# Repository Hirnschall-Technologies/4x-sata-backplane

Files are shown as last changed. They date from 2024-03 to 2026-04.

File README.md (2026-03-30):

## Custom 4x SATA Backplane for home-nas and servers
If you are interested in the design process behind this pcb, take a look at [this accompanying blog post.](https://blog.hirnschall.net/4x-sata-backplane)

### Why use a backplane
Using a backplane allows multiple disks to be connected to a single power-supply cable. For this a 4-pin molex connector is used as it can sustain the spinup current of 4 disks.

### How to order    
Download the the latest gerber-files from the [release tab](https://github.com/shirnschall/4x-sata-backplane/releases). Order then on e.g. jlcpcb.com.     
Use the following settings when ordering:
- PCB thickness: 1.6mm
- Layers: 4
- Impedance Control: yes, JLC04161H-7628
- Material type: FR4-Standard TG 135-140
- Copper weight: 1oz outer, 0.5oz inner
- Remove Order Number: Specify a location (remove if you want to)

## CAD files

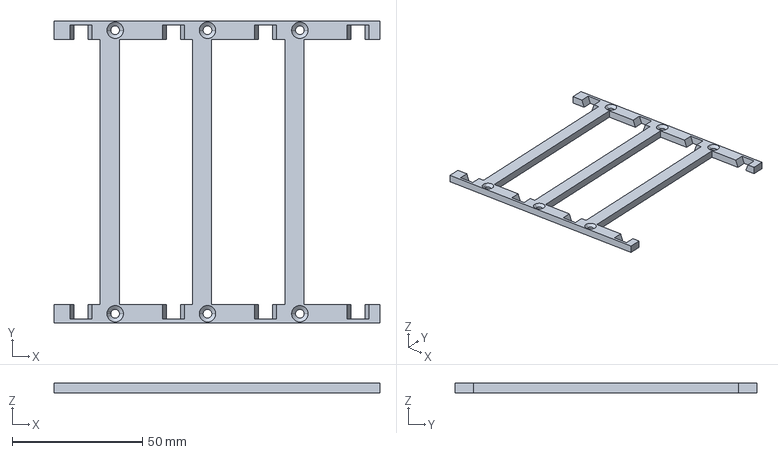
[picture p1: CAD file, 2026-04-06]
3d-print/stp/drive-cage-top.stp
125.0 x 115.7 x 4.00 mm

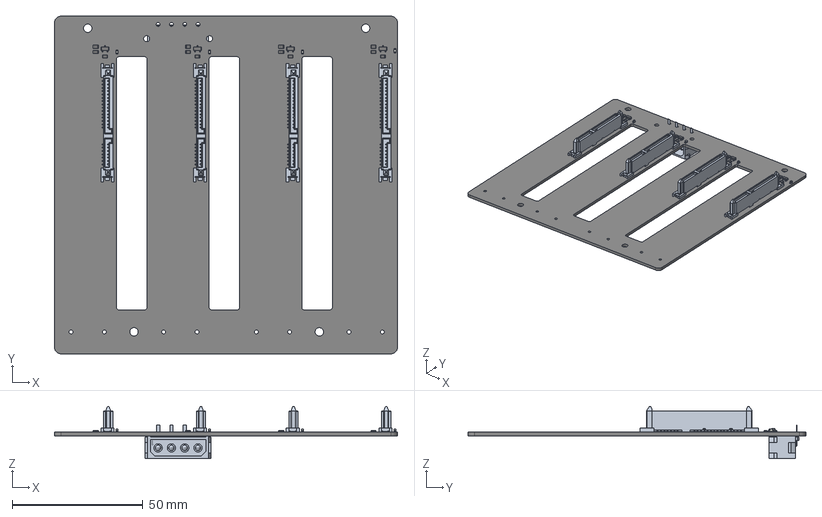
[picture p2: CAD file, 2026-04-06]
8x-sata-backplane/stp/4x-sata-backplane.step
131.0 x 129.0 x 20.0 mm
R_0805_2012Metric x 12
LED_0603_1608Metric x 4
SOT-23 x 4
8x-sata-backplane_PCB

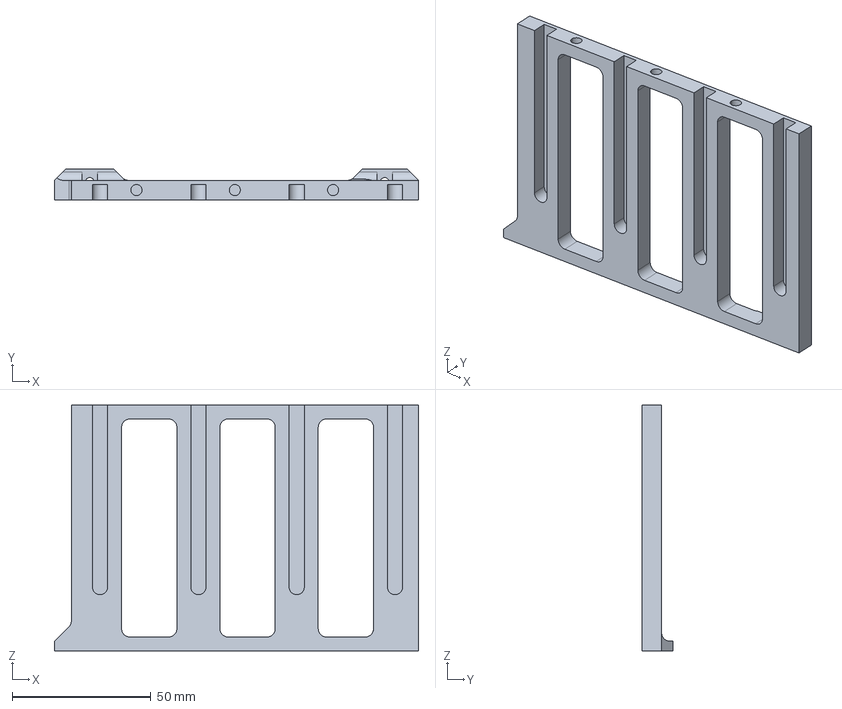
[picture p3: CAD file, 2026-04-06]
3d-print/stp/drive-cage.stp
131.0 x 11.0 x 88.5 mm

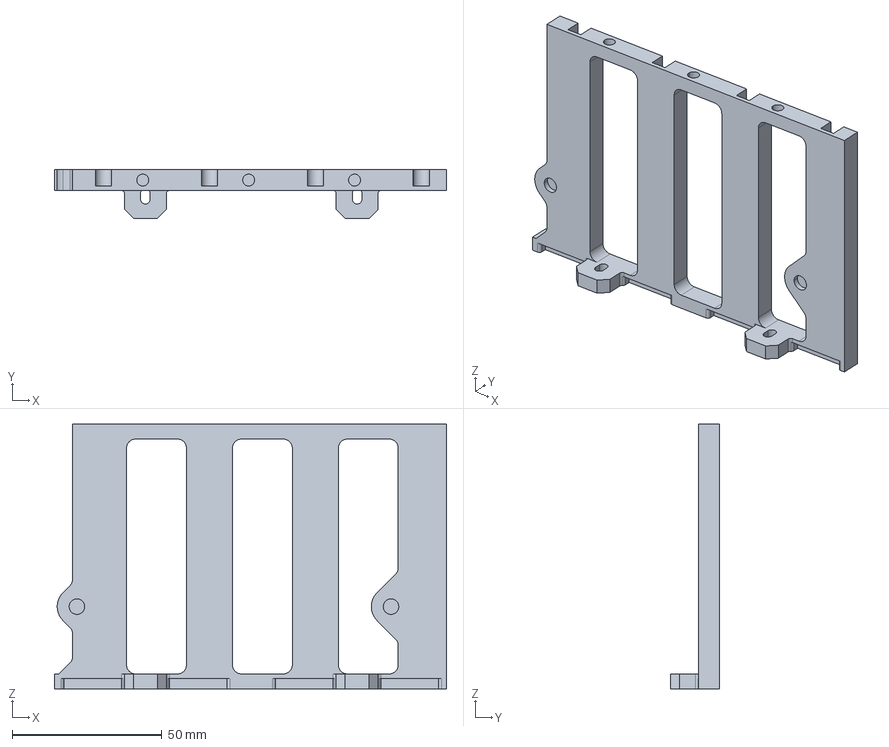
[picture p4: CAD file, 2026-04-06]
3d-print/stp/drive-cage-front.stp
131.0 x 16.3 x 88.5 mm

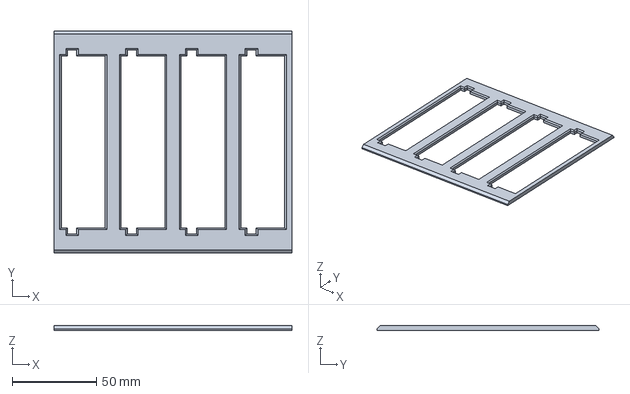
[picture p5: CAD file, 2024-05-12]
3d-print/stp/top-cover.stp
141.3 x 132.0 x 3.00 mm

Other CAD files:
3d-print/stp/drive-cage-back.stp

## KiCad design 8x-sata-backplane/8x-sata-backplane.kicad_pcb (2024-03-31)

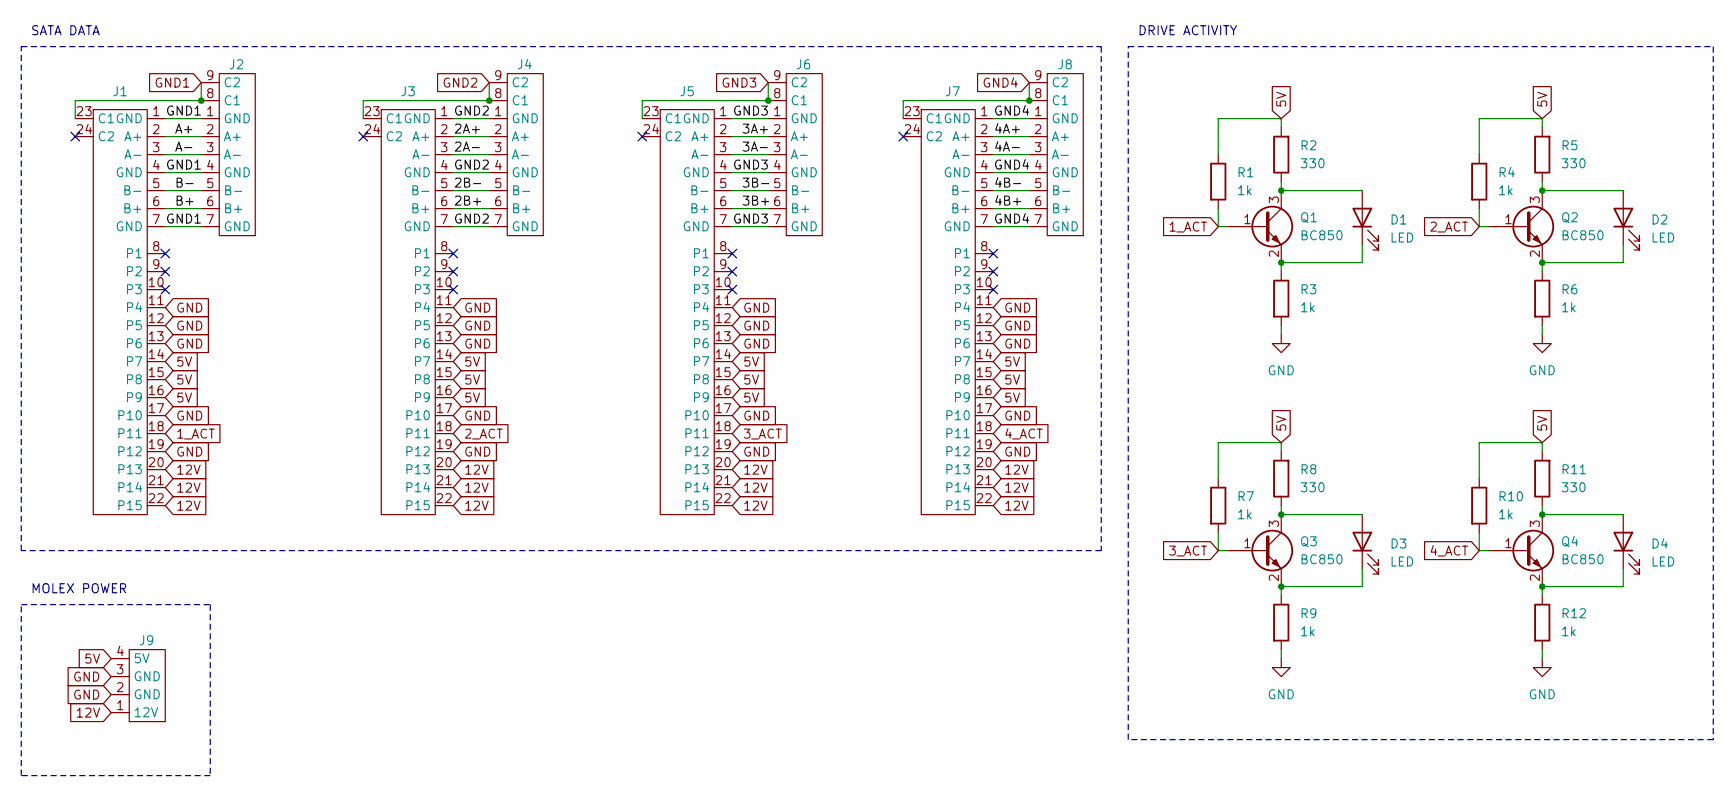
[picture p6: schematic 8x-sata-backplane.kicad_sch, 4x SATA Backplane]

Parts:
D1, D2, D3, D4: LED; LED_0603_1608Metric
J1, J3, J5, J7: sata-backplane-connector-vert
J2, J4, J6, J8: sata-data-connector
J9: 4-pin-molex-hdd
Q1, Q2, Q3, Q4: BC850; SOT-23
R1, R3, R4, R6, R7, R9, R10, R12: 1k; R_0805_2012Metric
R2, R5, R8, R11: 330; R_0805_2012Metric

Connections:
1_ACT: J1.18 (P11), Q1.1 (B), R1.2
2_ACT: J3.18 (P11), Q2.1 (B), R4.2
3_ACT: J5.18 (P11), Q3.1 (B), R7.2
4_ACT: J7.18 (P11), Q4.1 (B), R10.2
5V: J1.14 (P7), J1.15 (P8), J1.16 (P9), J3.14 (P7), J3.15 (P8), J3.16 (P9), J5.14 (P7), J5.15 (P8), J5.16 (P9), J7.14 (P7), J7.15 (P8), J7.16 (P9), J9.4 (5V), R1.1, R2.2, R4.1, R5.2, R7.1, R8.2, R10.1, R11.2
12V: J1.20 (P13), J1.21 (P14), J1.22 (P15), J3.20 (P13), J3.21 (P14), J3.22 (P15), J5.20 (P13), J5.21 (P14), J5.22 (P15), J7.20 (P13), J7.21 (P14), J7.22 (P15), J9.1 (12V)
/2A+: J3.2 (A+), J4.2 (A+)
/2A-: J3.3 (A-), J4.3 (A-)
/2B+: J3.6 (B+), J4.6 (B+)
/2B-: J3.5 (B-), J4.5 (B-)
/3A+: J5.2 (A+), J6.2 (A+)
/3A-: J5.3 (A-), J6.3 (A-)
/3B+: J5.6 (B+), J6.6 (B+)
/3B-: J5.5 (B-), J6.5 (B-)
/4A+: J7.2 (A+), J8.2 (A+)
/4A-: J7.3 (A-), J8.3 (A-)
/4B+: J7.6 (B+), J8.6 (B+)
/4B-: J7.5 (B-), J8.5 (B-)
/A+: J1.2 (A+), J2.2 (A+)
/A-: J1.3 (A-), J2.3 (A-)
/B+: J1.6 (B+), J2.6 (B+)
/B-: J1.5 (B-), J2.5 (B-)
GND: J1.11 (P4), J1.12 (P5), J1.13 (P6), J1.17 (P10), J1.19 (P12), J3.11 (P4), J3.12 (P5), J3.13 (P6), J3.17 (P10), J3.19 (P12), J5.11 (P4), J5.12 (P5), J5.13 (P6), J5.17 (P10), J5.19 (P12), J7.11 (P4), J7.12 (P5), J7.13 (P6), J7.17 (P10), J7.19 (P12), J9.2 (GND), J9.3 (GND), R3.2, R6.2, R9.2, R12.2
GND1: J1.1 (GND), J1.4 (GND), J1.7 (GND), J1.23 (C1), J2.1 (GND), J2.4 (GND), J2.7 (GND), J2.8 (C1), J2.9 (C2)
GND2: J3.1 (GND), J3.4 (GND), J3.7 (GND), J3.23 (C1), J4.1 (GND), J4.4 (GND), J4.7 (GND), J4.8 (C1), J4.9 (C2)
GND3: J5.1 (GND), J5.4 (GND), J5.7 (GND), J5.23 (C1), J6.1 (GND), J6.4 (GND), J6.7 (GND), J6.8 (C1), J6.9 (C2)
GND4: J7.1 (GND), J7.4 (GND), J7.7 (GND), J7.23 (C1), J8.1 (GND), J8.4 (GND), J8.7 (GND), J8.8 (C1), J8.9 (C2)
unnamed: D1.2 (A), Q1.3 (C), R2.1
unnamed: D1.1 (K), Q1.2 (E), R3.1
unnamed: D2.2 (A), Q2.3 (C), R5.1
unnamed: D2.1 (K), Q2.2 (E), R6.1
unnamed: D3.2 (A), Q3.3 (C), R8.1
unnamed: D3.1 (K), Q3.2 (E), R9.1
unnamed: D4.2 (A), Q4.3 (C), R11.1
unnamed: D4.1 (K), Q4.2 (E), R12.1

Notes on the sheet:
DRIVE ACTIVITY
SATA DATA
MOLEX POWER

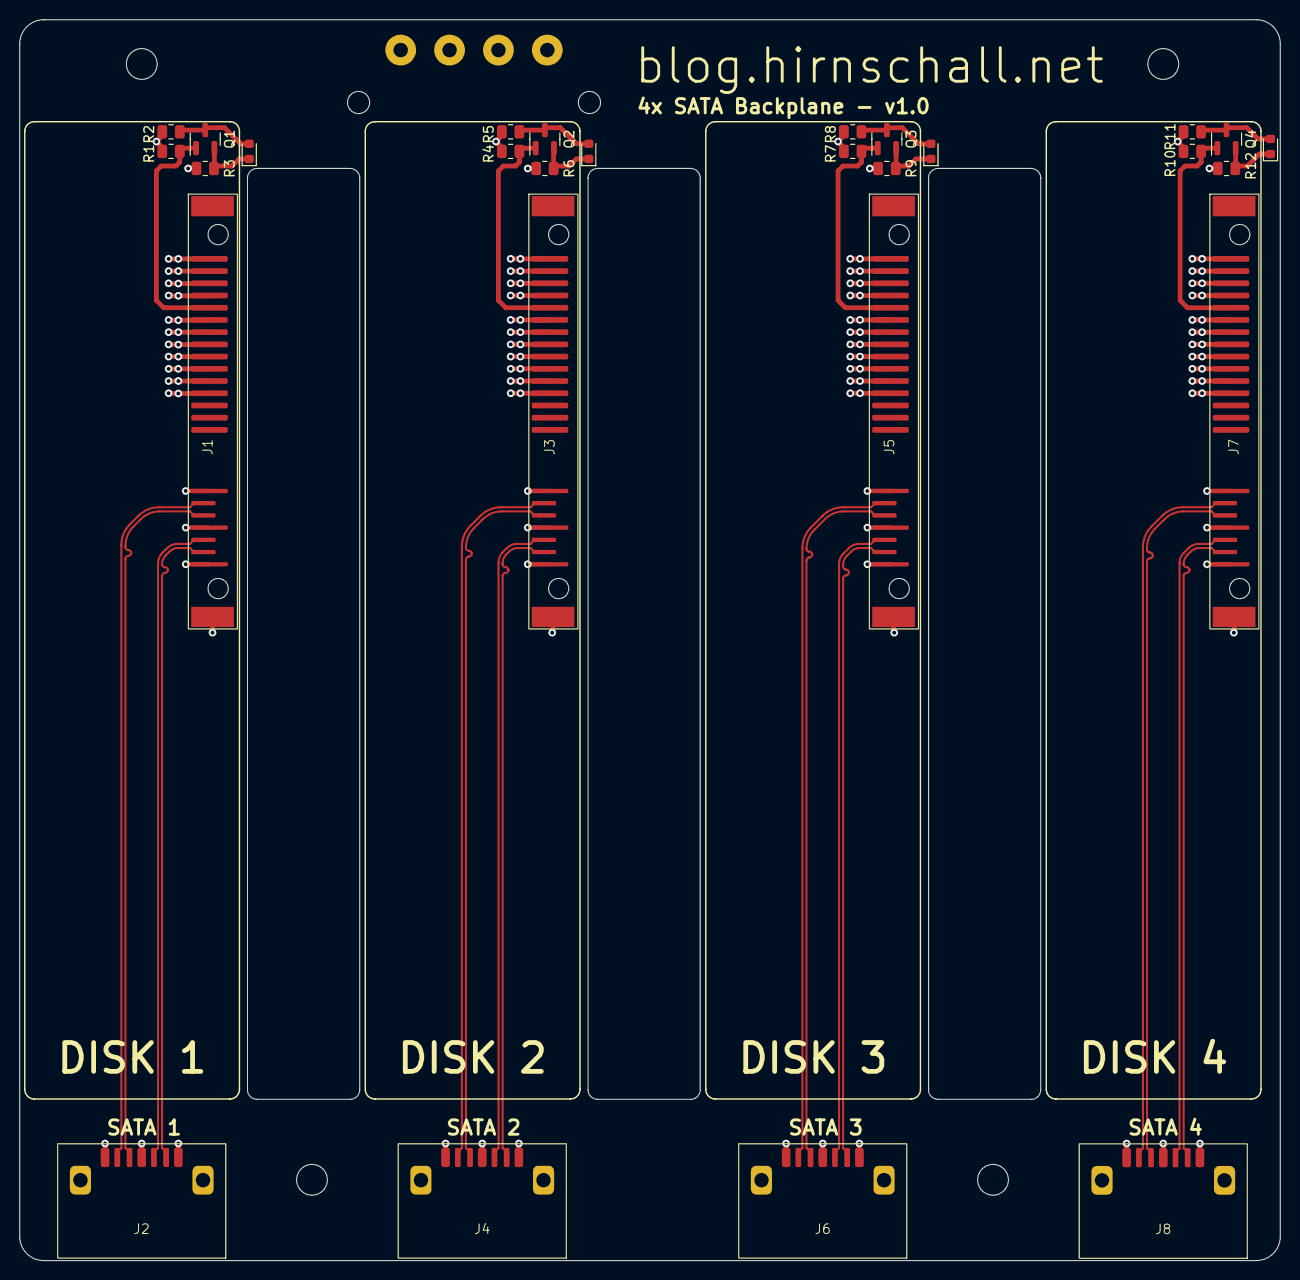
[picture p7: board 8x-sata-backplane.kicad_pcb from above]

Board: 4 copper layers, 131.0 x 129.0 mm, 29 parts (1 on the bottom side), 35 nets.

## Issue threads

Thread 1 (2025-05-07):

Missing blog post

nebulorum, 2025-05-07:
I have been looking for something like this, but the referred blog post is not working. I would also like to know if this support hotswap and if you looked into staggered spin up?

shirnschall, 2025-05-07:
Hi, yes the blogpost is unfortunately not done yet. Hotswap is supported if the sata controller supports it as the backplane itself is just an extension of the sata cable. I have looked into staggered spinup but I cannot remember what the outcome was off the top of my head. I will check if staggered spinup is a problem and get back to you!

nebulorum, 2025-05-07:
My understanding is that there have to be some passive components on the backplane to support hotswap (but I'm just a hobbies). I'll wait for the blog post.

nebulorum, 2025-05-14:
Thanks for the information, I have been looking at both on Ali and seems they use a decoupling capacitor on +12V and +5.
In [SATA SpecRevision 3.5_Gold](https://sata-io.org/system/files/specifications/SerialATA_Revision_3_5_Gold.pdf)  Pg 281, section 6.14.3 shows the pre-charge, fundamentally you need a small resistor on the pins that connect first.
* These are P13, P7 as shown on page 227
* Example of typical resistor is 10-20 Ohms.
Many board have both the resistor and the capacitors. Pin 11 still confuses me a bit since it has this dual role (also described in the spec).

shirnschall, 2025-05-14:
Thank you very much for the pdf! I will add the precharge resistors

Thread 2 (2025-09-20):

Schematic

ilium007, 2025-09-20:
Any chance of getting a PDF schematic uploaded?

shirnschall, 2025-09-20:
[4x-sata-backplane-schematic.pdf](https://github.com/user-attachments/files/22440960/4x-sata-backplane-schematic.pdf)

Closed 2025-09-20.

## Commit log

2024-03-25 initial design of v1.0
    [2x-sata.kicad_sch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]
2024-05-07 v1.0 html bom
2024-05-12 inital test of disk shape and spacing for cage
    [top-cover.CATPart, top-cover.stp]
2026-04-04 kicad mechanical step export
    [4x-sata-backplane.step]
2026-04-06 add updated step files for drive cage, and pcb step export
    [4x-sata-backplane.step, drive-cage-back.stp, drive-cage-front.stp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]
